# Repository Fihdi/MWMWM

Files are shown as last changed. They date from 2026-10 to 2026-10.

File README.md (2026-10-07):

# 6hp Wavefolder


MWMWM is a 7 to 1 Wavefolder based on [Daveys Deadband](https://github.com/DaveyGraham/Daveys_Deadband) and Buchlas wavefolding method. At the maximum amount of wavefolding, a single wave cycle gets converted into seven cycles on the output.

The **FOLD** and the **CV** knob settings control the amount of wavefolding. 

**OFFSET** is the second input and is summed to the **IN** signal. Like the **OFFSET** knob, it can be used to offset the **IN** signal.

Fully analog design allows for audio rate modulation. Every input and output is DC biased and thus the module can be used with CV signals as well.

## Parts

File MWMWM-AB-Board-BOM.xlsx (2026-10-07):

 |  |  | MWMWM AB-Board BOM
Item # | *Designator | *Qty | Manufacturer | *Mfg Part # | Description / Value | *Package/Footprint | Type | Your Instructions / Notes
1 | C12,C17 | 2 |  | C28323 | 1u | Capacitor_SMD:C_0805_2012Metric
2 | C13,C14,C15,C16 | 4 |  | C1790 | 100p | Capacitor_SMD:C_0805_2012Metric
3 | C18,C19,C20,C21 | 4 |  | C49678 | 100n | Capacitor_SMD:C_0805_2012Metric
4 | D1 | 1 |  |  | LED_Dual_Bidirectional | LED_THT:LED_D5.0mm |  | DNP
5 | D3 | 1 |  |  | LED | LED_THT:LED_D3.0mm |  | DNP
6 | D14,D15,D16,D17,D18,D19,D20,D21,D22,D23,D24,D25,D26,D27,D28,D29 | 16 |  | C917117 | 1N4148 | Diode_SMD:D_SOD-323_HandSoldering
7 | J1 | 1 |  |  | Conn_02x05_Odd_Even | Connector_IDC:IDC-Header_2x05_P2.54mm_Vertical |  | DNP
8 | J17,J18,J19,J20 | 4 |  |  | AudioJack2 | Library:MonoTRS |  | DNP
9 | Q1 | 1 |  | C148244 | BC857 | Package_TO_SOT_SMD:SOT-23
10 | Q2 | 1 |  | C475630 | BC847 | Package_TO_SOT_SMD:SOT-23
11 | R7,R8,R9,R10,R11,R12,R13,R14,R15,R16,R17,R18,R19,R20,R21,R22,R40,R50 | 18 |  | C17414 | 10k | Resistor_SMD:R_0805_2012Metric
12 | R23,R24,R25,R26,R27,R28,R29,R30,R31,R34,R35,R36,R37,R42,R43,R48,R49 | 17 |  | C2907217 | 100k | Resistor_SMD:R_0805_2012Metric
13 | R32 | 1 |  | C275642 | 1M5 | Resistor_SMD:R_0805_2012Metric
14 | R33,R38,R39 | 3 |  | C95781 | 1k | Resistor_SMD:R_0805_2012Metric
15 | R41,R44 | 2 |  | C2930202 | 47k | Resistor_SMD:R_0805_2012Metric
16 | R45,R46 | 2 |  | C17560 | 22k | Resistor_SMD:R_0805_2012Metric
17 | R47 | 1 |  | C2907326 | 4k7 | Resistor_SMD:R_0805_2012Metric
18 | RV1,RV2,RV3 | 3 |  |  | 100k | Potentiometer_THT:Potentiometer_Alpha_RD901F-40-00D_Single_Vertical |  | DNP
19 | U1,U2,U3 | 3 |  | C4370424 | TL074 | Package_SO:TSSOP-14_4.4x5mm_P0.65mm
20 | U4 | 1 |  | C174050 | LM13700 | Package_SO:SOIC-16_3.9x9.9mm_P1.27mm
Need a quick and accurante quote? Need an efficient production? Please read SMT Ordering Necessary Files & Info in 1 minute. Thank you very much!
Click for Instructions on How to Create a BOM (https://www.pcbway.com/blog/PCB_Assembly/How_to_Build_a_BOM__Bill_Of_Materials_.html)

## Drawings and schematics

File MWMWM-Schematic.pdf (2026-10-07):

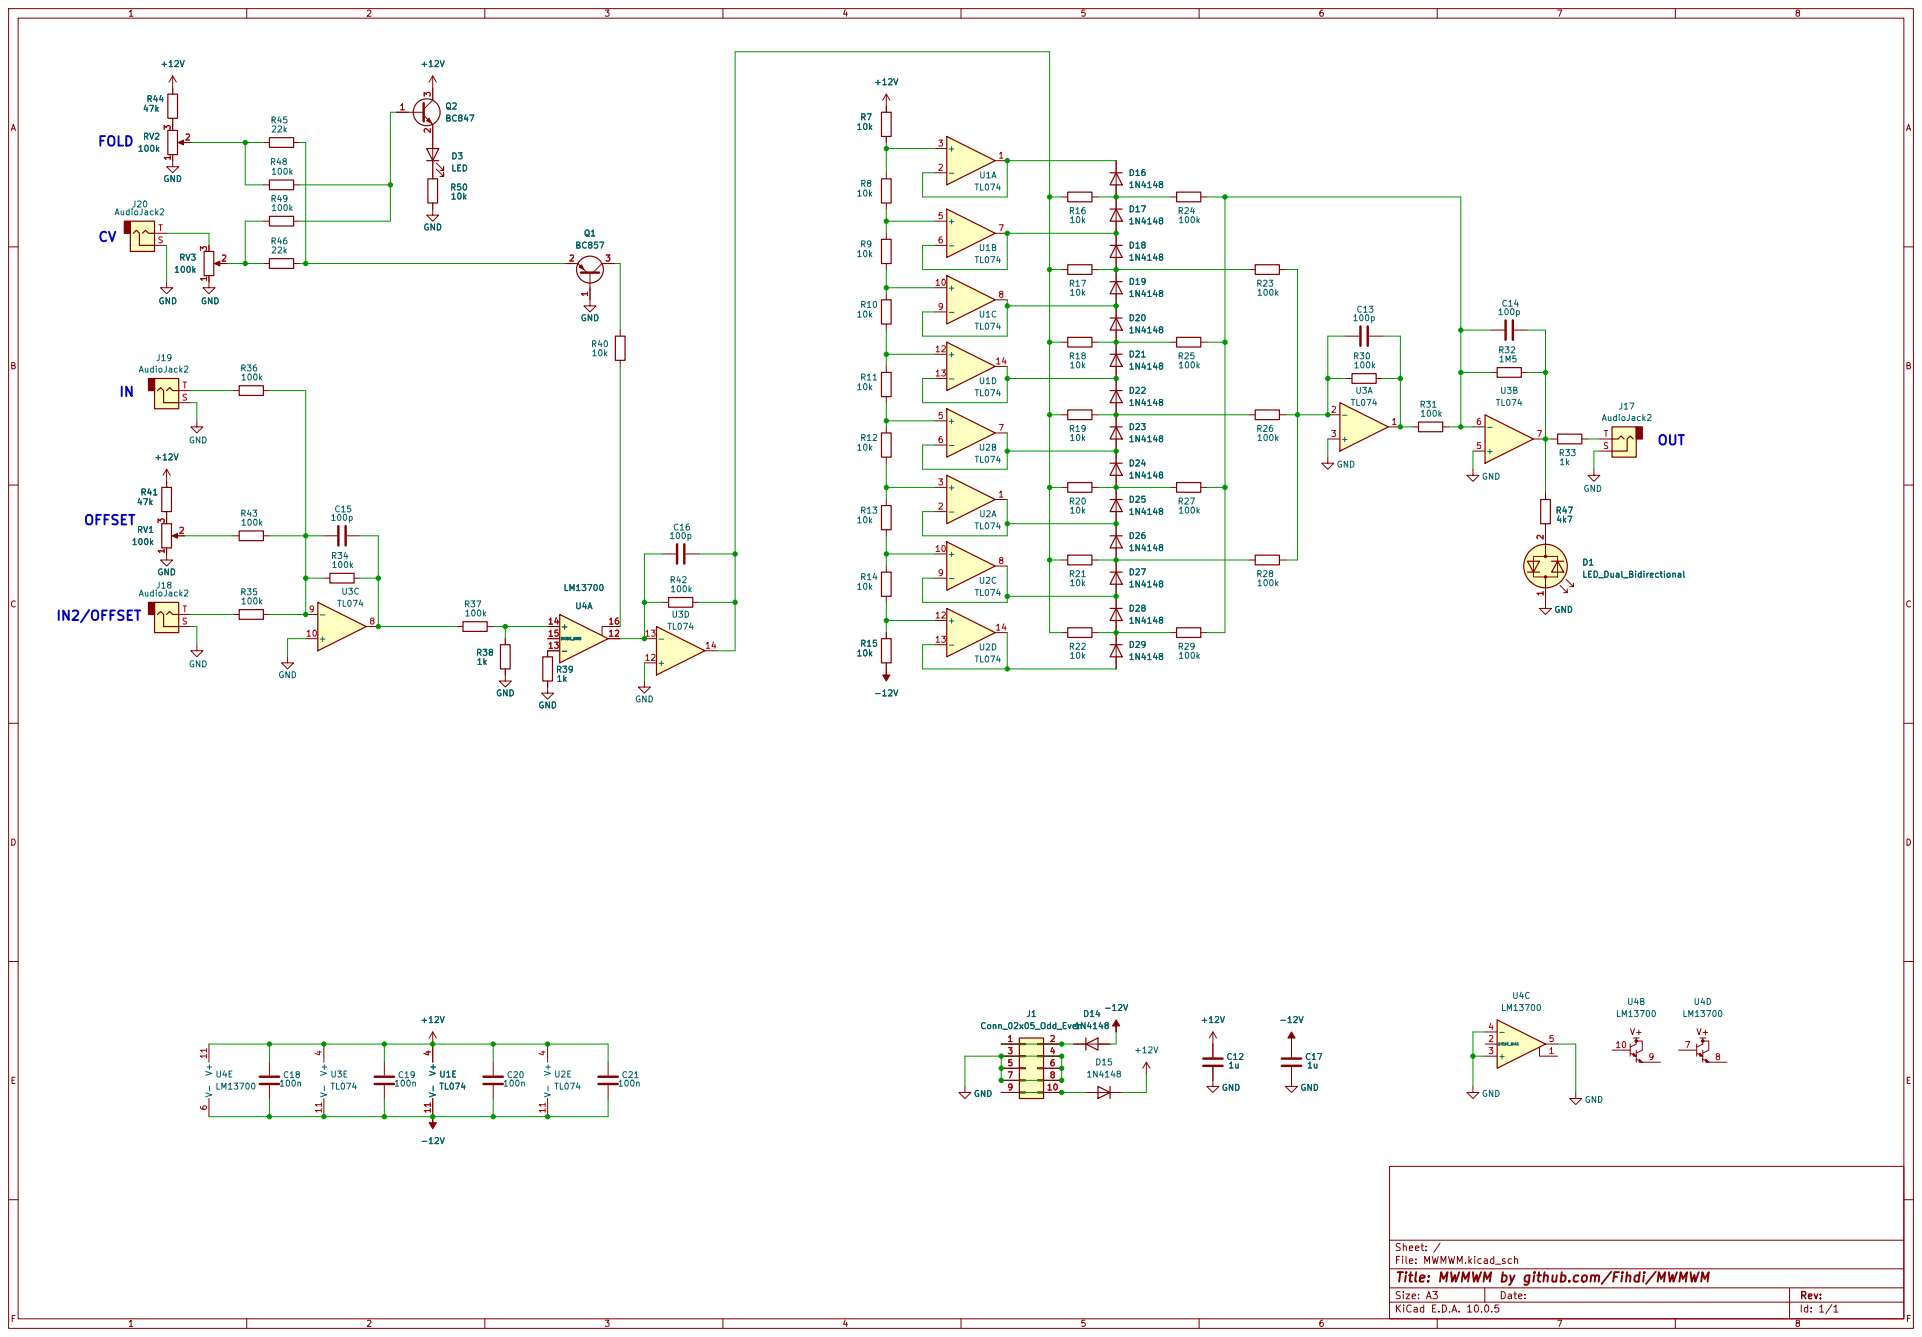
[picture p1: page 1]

5 5 | 6 6
7 7 | 8 8

Sheet: /
File: MWMWM.kicad_sch
Title: MWMWM by github.com/Fihdi/MWMWM

Size: A3 | Rev: | F Date:
KiCad E.D.A. 10.0.5 | Id: 1/1

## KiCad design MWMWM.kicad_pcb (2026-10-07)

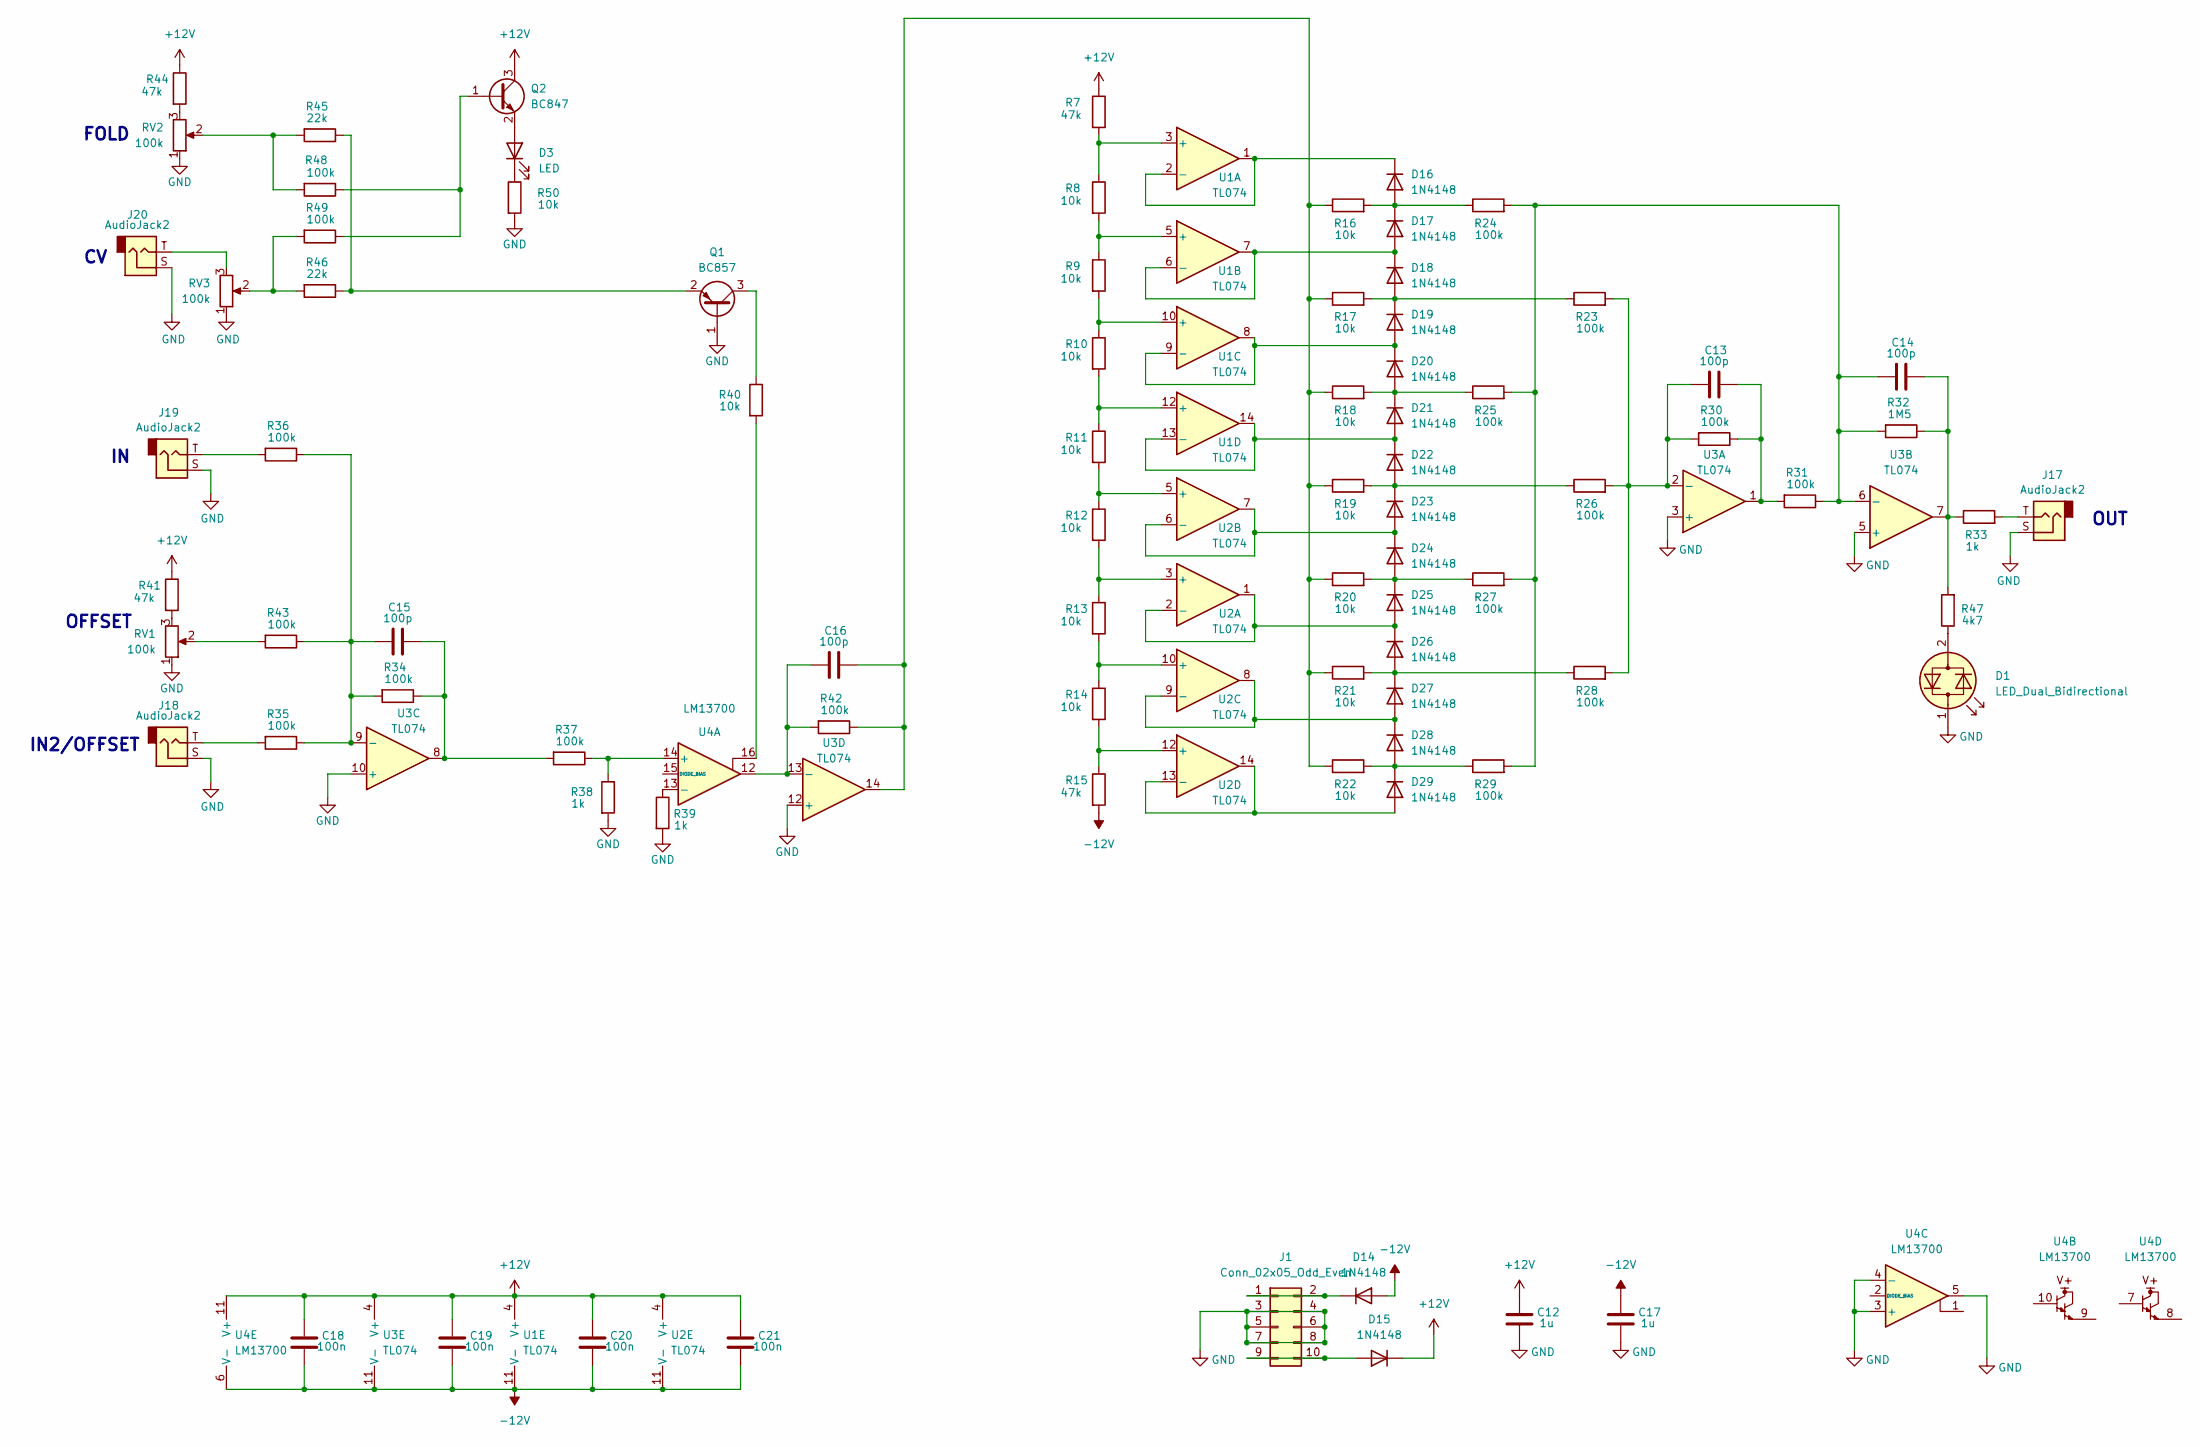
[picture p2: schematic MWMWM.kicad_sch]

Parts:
C12, C17: 1u; C_0805_2012Metric
C13, C14, C15, C16: 100p; C_0805_2012Metric
C18, C19, C20, C21: 100n; C_0805_2012Metric
D1: LED_Dual_Bidirectional; LED_D5.0mm
D3: LED; LED_D3.0mm
D14, D15, D16, D17, D18, D19, D20, D21, D22, D23, D24, D25, D26, D27, D28, D29: 1N4148; D_SOD-323_HandSoldering
J1: Conn_02x05_Odd_Even; IDC-Header_2x05_P2.54mm_Vertical
J17, J18, J19, J20: AudioJack2; MonoTRS
Q1: BC857; SOT-23
Q2: BC847; SOT-23
R7, R15, R41, R44: 47k; R_0805_2012Metric
R8, R9, R10, R11, R12, R13, R14, R16, R17, R18, R19, R20, R21, R22, R40, R50: 10k; R_0805_2012Metric
R23, R24, R25, R26, R27, R28, R29, R30, R31, R34, R35, R36, R37, R42, R43, R48, R49: 100k; R_0805_2012Metric
R32: 1M5; R_0805_2012Metric
R33, R38, R39: 1k; R_0805_2012Metric
R45, R46: 22k; R_0805_2012Metric
R47: 4k7; R_0805_2012Metric
RV1, RV2, RV3: 100k; Potentiometer_Alpha_RD901F-40-00D_Single_Vertical
U1, U2, U3: TL074; TSSOP-14_4.4x5mm_P0.65mm
U4: LM13700; SOIC-16_3.9x9.9mm_P1.27mm

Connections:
+12V: C12.1, C18.1, C19.1, C20.1, C21.1, D15.1 (K), Q2.3 (C), R7.1, R41.1, R44.1, U1.4 (V+), U2.4 (V+), U3.4 (V+), U4.11 (V+)
-12V: C17.1, C18.2, C19.2, C20.2, C21.2, D14.2 (A), R15.2, U1.11 (V-), U2.11 (V-), U3.11 (V-), U4.6 (V-)
GND: C12.2, C17.2, D1.1 (KA), J1.3, J1.4, J1.5, J1.6, J1.7, J1.8, J17.S, J18.S, J19.S, J20.S, Q1.1 (B), R38.2, R39.2, R50.2, RV1.1, RV2.1, RV3.1, U3.3 (+), U3.5 (+), U3.10 (+), U3.12 (+), U4.3 (+), U4.4 (-), U4.5
unnamed: C13.2, R30.1, R31.2, U3.1
unnamed: C14.2, R32.1, R33.1, R47.2, U3.7
unnamed: C15.2, R34.1, R37.2, U3.8
unnamed: C16.2, R16.1, R17.1, R18.1, R19.1, R20.1, R21.1, R22.1, R42.1, U3.14
unnamed: D1.2 (AK), R47.1
unnamed: D3.2 (A), Q2.2 (E)
unnamed: D3.1 (K), R50.1
unnamed: D14.1 (K), J1.1, J1.2
unnamed: D15.2 (A), J1.9, J1.10
unnamed: D16.2 (A), D17.1 (K), R16.2, R24.1
unnamed: D16.1 (K), U1.1, U1.2 (-)
unnamed: D17.2 (A), D18.1 (K), U1.6 (-), U1.7
unnamed: D18.2 (A), D19.1 (K), R17.2, R23.1
unnamed: D19.2 (A), D20.1 (K), U1.8, U1.9 (-)
unnamed: D20.2 (A), D21.1 (K), R18.2, R25.1
unnamed: D21.2 (A), D22.1 (K), U1.13 (-), U1.14
unnamed: D22.2 (A), D23.1 (K), R19.2, R26.1
unnamed: D23.2 (A), D24.1 (K), U2.6 (-), U2.7
unnamed: D24.2 (A), D25.1 (K), R20.2, R27.1
unnamed: D25.2 (A), D26.1 (K), U2.1, U2.2 (-)
unnamed: D26.2 (A), D27.1 (K), R21.2, R28.1
unnamed: D27.2 (A), D28.1 (K), U2.8, U2.9 (-)
unnamed: D28.2 (A), D29.1 (K), R22.2, R29.1
unnamed: D29.2 (A), U2.13 (-), U2.14
unnamed: J17.T, R33.2
unnamed: J18.T, R35.2
unnamed: J19.T, R36.2
unnamed: J20.T, RV3.3
unnamed: Q1.3 (C), R40.1
unnamed: Q1.2 (E), R45.1, R46.1
unnamed: Q2.1 (B), R48.1, R49.1
unnamed: R40.2, U4.16
unnamed: R41.2, RV1.3
unnamed: R43.2, RV1.2
unnamed: R44.2, RV2.3
unnamed: R45.2, R48.2, RV2.2
unnamed: R46.2, R49.2, RV3.2
unnamed: R7.2, R8.1, U1.3 (+)
unnamed: R8.2, R9.1, U1.5 (+)
unnamed: R9.2, R10.1, U1.10 (+)
unnamed: R10.2, R11.1, U1.12 (+)
unnamed: R12.2, R13.1, U2.3 (+)
unnamed: R11.2, R12.1, U2.5 (+)
unnamed: R13.2, R14.1, U2.10 (+)
unnamed: R14.2, R15.1, U2.12 (+)
unnamed: C13.1, R23.2, R26.2, R28.2, R30.2, U3.2 (-)
unnamed: C14.1, R24.2, R25.2, R27.2, R29.2, R31.1, R32.2, U3.6 (-)
unnamed: C15.1, R34.2, R35.1, R36.1, R43.1, U3.9 (-)
unnamed: C16.1, R42.2, U3.13 (-), U4.12
unnamed: R37.1, R38.1, U4.14 (+)
unnamed: R39.1, U4.13 (-)

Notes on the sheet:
OUT
IN2/OFFSET
OFFSET
FOLD

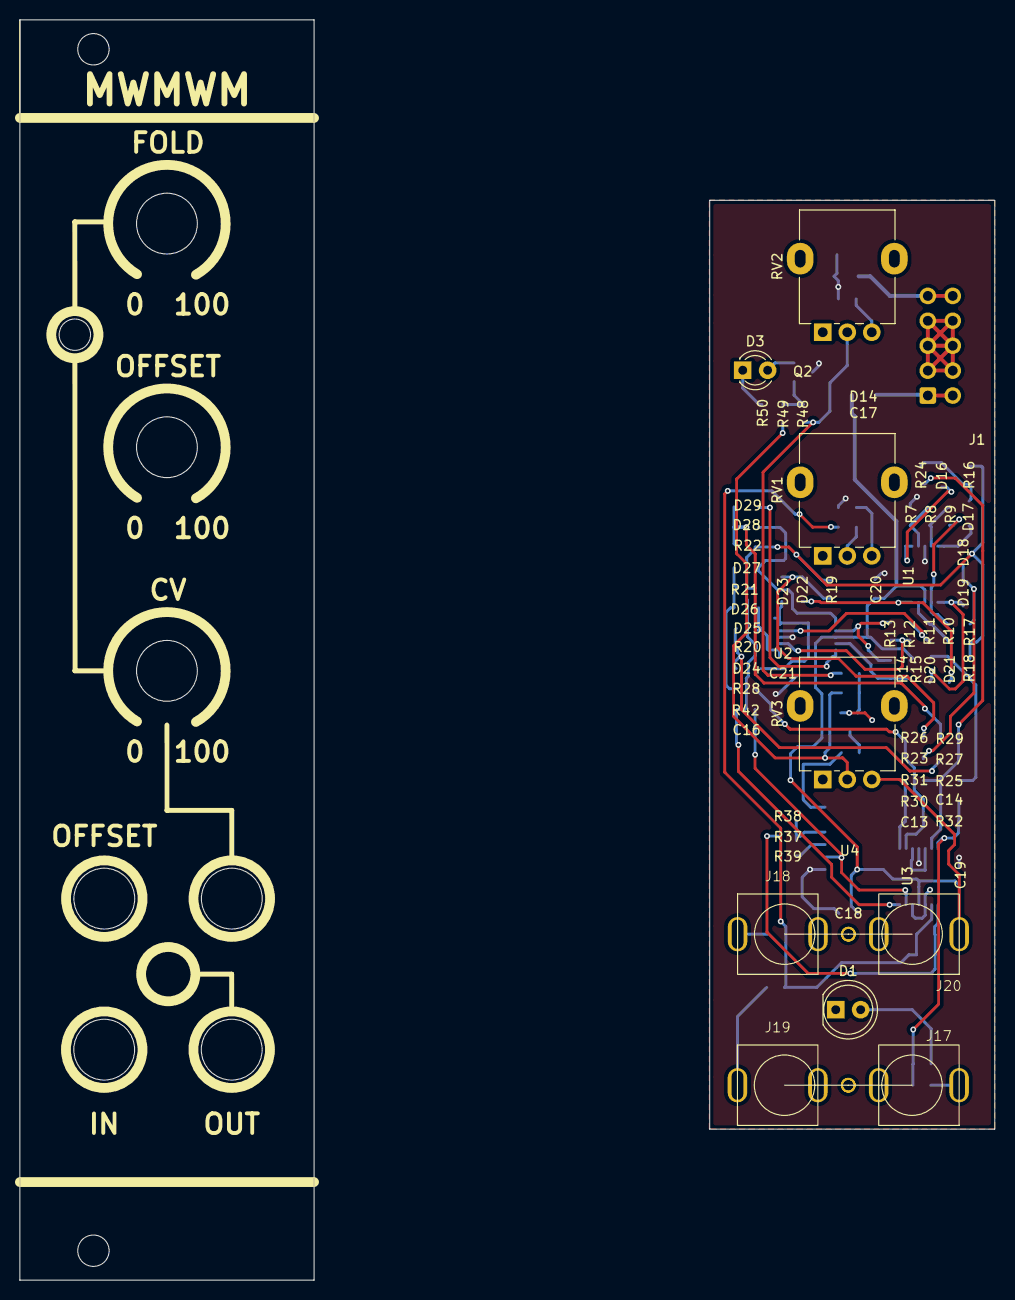
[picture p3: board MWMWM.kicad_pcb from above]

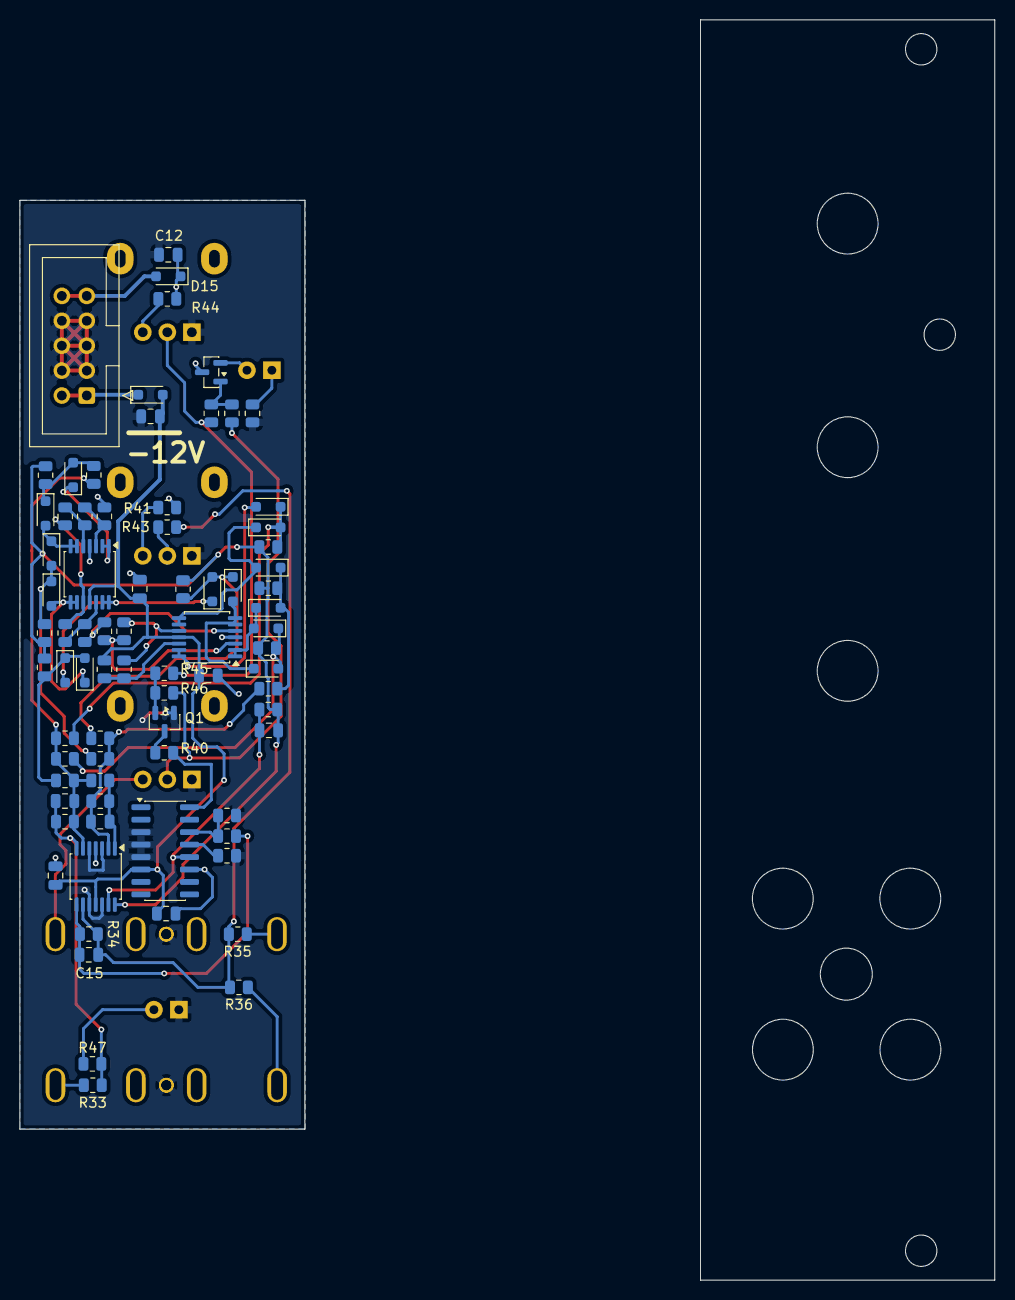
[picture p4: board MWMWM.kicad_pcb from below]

Board: 2 copper layers, 29.1 x 94.7 mm, 86 parts (77 on the bottom side), 54 nets.
